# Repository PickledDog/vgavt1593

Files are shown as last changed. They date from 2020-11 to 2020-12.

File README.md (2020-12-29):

# vgavt1593
 Marco Maccaferri's Propeller VT100 Terminal, in a box
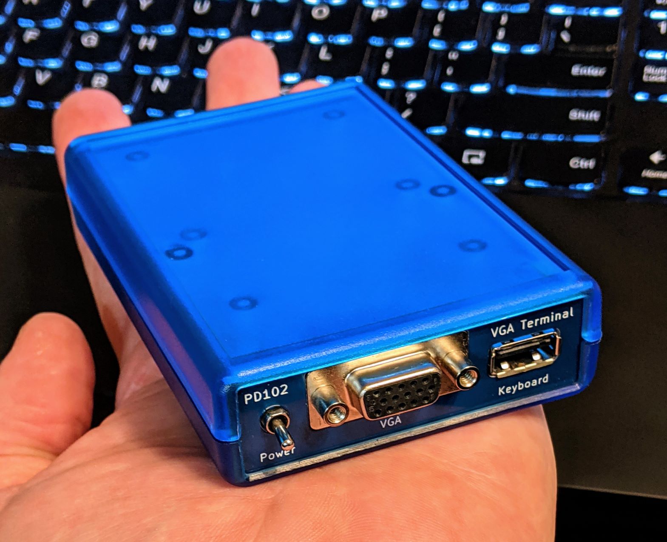
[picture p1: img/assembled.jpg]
Assembled VGA terminal


## Overview
This is a remix of Marco Maccaferri's [VGA Serial Terminal](https://github.com/maccasoft/propeller-vt100-terminal) for RC2014. It is specifically adapted to be used with Stephen C Cousins' [SC131](https://smallcomputercentral.wordpress.com/sc131-z180-pocket-computer/) Z180 pocket computer. It fits into the same Hammond 1593N enclosure, making for a neat and tidy setup when combined with an SC131. Of course, it can also be used with any other retrocomputer or device that expects a VT100-like terminal, connected over "TTL-Serial" raw RS232.

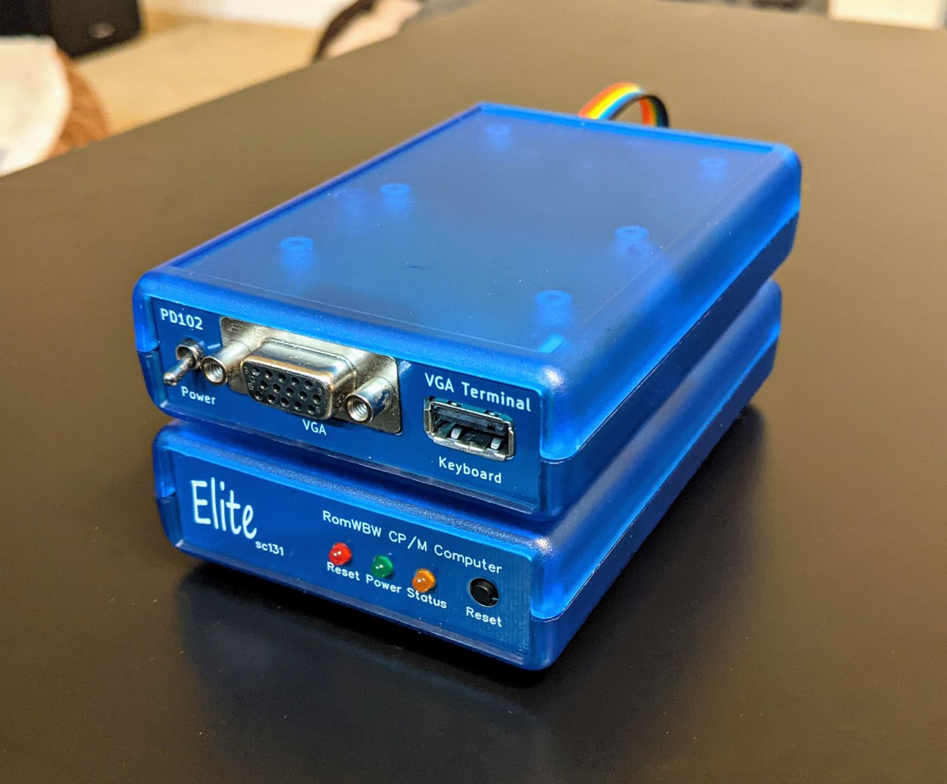
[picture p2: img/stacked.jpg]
Stacked with SC131

VGA terminal stacked with SC131 computer

## Terminal description
Details about the terminal itself are covered by Marco's project (this remix largely just changes the form factor). For detailed information, see his [project page](https://github.com/maccasoft/propeller-vt100-terminal).

## Serial interfaces
Connection to a computer is provided through an FTDI-style pin header, wired to the same pinout. Specifically, it is wired as a DTE (just like an FTDI dongle), so it can be wired directly to a DCE (like an SC131). A second *passthrough* port is provided to permit a PC connection to the same computer. This passthrough port is wired as a DCE, so FTDI cables can be connected directly. An AND gate mixes the terminal and passthrough connections together, so both can be used simultaneously. Transmitting from both at the same time will send gibberish; in testing this is relatively rare, and XMODEM at least will retransmit if this happens.

## Usage
This terminal lets you use your SC131 (or other retrocomputer) standalone, without dependency on another computer. In addition, a modern computer can be connected to the passthrough port as needed. This is useful for sending files over XMODEM, for example.

### Power
5V power is received through a standard 5.5/2.1mm barrel jack connection, center positive. The device optionally sends power to the connected computer (selectable by a jumper on JP1 - this is expected by SC131). In most cases, JP1 should be left installed. Wall adapters in this voltage and configuration are common, or a USB to 5.5mm cable can be used (examples [here](https://www.ebay.com/sch/i.html?_nkw=usb+to+5.5mm)).

### Why are the plugs on the front?
Because I ran out of room on the enclosure's panels. Between two FTDI headers, 5V in, reset, power switch, VGA, and USB, there wasn't even room left for a power LED. The serial ports are on the same side as the SC131 ones at least, so those can be connected together cleanly with a [6-pin Dupont cable](https://www.ebay.com/sch/i.html?_nkw=6+pin+dupont+cable).

### Initial setup
The parts specified are not pre-programmed; they will need to be programmed before use. Either a [Prop-Plug](https://www.mouser.com/ProductDetail/32201) can be used on the assembled board, or a [TL866](https://www.ebay.com/sch/i.html?_nkw=tl866ii+plus) or [CH341](https://www.ebay.com/sch/i.html?_nkw=ch341a+programmer) can be used on the bare EEPROM. Instructions (and firmware) for programming can be found at the same [link](https://github.com/maccasoft/propeller-vt100-terminal) as above.

## Part selection
Bill Of Materials and part references are below. Note that the right-angle headers have to be a specific type to align with the panel PCBs - they need to have the plastic "end stopper" on the "business" side of the angle, *not* the side you solder to the PCB. Headers from [Pololu](https://www.pololu.com/product/967), [Sparkfun](https://www.sparkfun.com/products/553), and [Adafruit](https://www.adafruit.com/product/1540) are like this, as is the Mouser listing below. Most eBay etc listings are ***not*** like this, and will not align correctly. If the appropriate headers cannot be sourced, double-row right-angle headers can be used, with the top row of pins removed.

The other headers can be snapped from regular breakaway header, for which eBay is substantially cheaper; the Mouser listings are provided for convenience. The specified parts are just the ones I used, and can be substituted as needed - Mouser links provided for convenience and reference. The case is available in other colours!

| Reference | Value | Qty | Mouser link |
| --- | ----- | --- | --- |
| BZ1 | Piezo buzzer | 1 | [TDK PS1240P02BT](https://www.mouser.com/ProductDetail/810-PS1240P02BT) |
| C1, C2 | 1μF ceramic | 2 | [TDK FG18X5R1H105KRT06](https://www.mouser.com/ProductDetail/FG18X5R1H105KRT06) |
| C3-C7 | 100nF ceramic | 5 | [KEMET C315C104M5U5TA](https://www.mouser.com/ProductDetail/C315C104M5U5TA7303) |
| C8 | 10μF electrolytic | 1 | [Nichicon UMA1E100MDD](https://www.mouser.com/ProductDetail/UMA1E100MDD) |
| J1 | 5.5/2.1mm barrel socket | 1 | [CUI PJ-002A](https://www.mouser.com/ProductDetail/490-PJ-002A) |
| J2 | 1x4 header | 1 | [Amphenol 10129378-904002BLF](https://www.mouser.com/ProductDetail/10129378-904002BLF) |
| J3, J4 | 1x6 right-angle header | 2 | [Amphenol 10129379-906003BLF](https://www.mouser.com/ProductDetail/10129379-906003BLF) |
| J5 | USB A socket | 1 | [Amphenol FCI 87520-1110BLF](https://www.mouser.com/ProductDetail/649-87520-1110BLF) |
| J6 | D-Sub HD-15 Female | 1 | [TE 2311763-1](https://www.mouser.com/ProductDetail/571-2311763-1) |
| JP1 | 1x2 header | 1 | [Amphenol 10129378-902002BLF](https://www.mouser.com/ProductDetail/10129378-902002BLF) |
| | jumper | 1 | [Harwin M7583-46](https://www.mouser.com/ProductDetail/M7583-46)
| R1, R4 | 10kΩ resistor | 2 | [Yageo CFR-25JT-52-10K](https://www.mouser.com/ProductDetail/CFR-25JT-52-10K) |
| R2, R3 | 4k7Ω resistor | 2 | [Yageo CFR-25JT-52-4K7](https://www.mouser.com/ProductDetail/CFR-25JT-52-4K7) |
| R5, R8 | 47kΩ resistor | 2 | [Yageo CFR-25JT-52-47K](https://www.mouser.com/ProductDetail/CFR-25JT-52-47K) |
| R6, R7 | 47Ω resistor | 2 | [Yageo CFR-25JT-52-47R](https://www.mouser.com/ProductDetail/CFR-25JT-52-47R) |
| R9, R12, R15 | 261Ω resistor | 3 | [Yageo MFR-25FRF52-261R](https://www.mouser.com/ProductDetail/603-MFR-25FRF52-261R) |
| R10, R13, R16 | 510Ω resistor | 3 | [Yageo MFR-25FTE52-510R](https://www.mouser.com/ProductDetail/603-MFR-25FTE52-510R) |
| R11, R14, R17-R19 | 120Ω resistor | 5 | [Yageo MFR-25FTF52-120R](https://www.mouser.com/ProductDetail/603-MFR-25FTF52-120R) |
| SW1 | SPDT toggle sw, right-angle | 1 | [Grayhill 34CMSP12B2M7QT](https://www.mouser.com/ProductDetail/706-34CMSP12B2M7QT) |
| SW2 | Right-angle tact sw 8.3mm | 1 | [C&K PTS645VL832LFS](https://www.mouser.com/ProductDetail/611-PTS645VL832) |
| U1 | Parallax Propeller | 1 | [Parallax Propeller P8X32A-D40](https://www.mouser.com/ProductDetail/619-P8X32A-D40) |
| | socket | 1 | [Amphenol DILB40P-223TLF](https://www.mouser.com/ProductDetail/DILB40P-223TLF) |
| U2 | 24LC256 EEPROM | 1 | [Microchip 24LC256](https://www.mouser.com/ProductDetail/579-24LC256-I-P) |
| | socket | 1 | [Amphenol DILB8P-223TLF](https://www.mouser.com/ProductDetail/DILB8P-223TLF) |
| U3 | MCP1700-330 | 1 | [Microchip MCP1700-3302E/TO](https://www.mouser.com/ProductDetail/579-MCP1700-3302E-TO) |
| U4 | 74HC08 | 1 | [TI SN74HC08AN](https://www.mouser.com/ProductDetail/595-SN74HC08AN) |
| X1 | 5MHz HC-49 crystal | 1 | [ECS ECS-50-18-4XEN](https://www.mouser.com/ProductDetail/520-50-18-4XEN) |
| Case | Hammond 1593N | 1 | [Hammond 1593NTBU](https://www.mouser.com/ProductDetail/546-1593NTBU) |
| Screws | Hammond self-tapping | (some of) | [Hammond 1593ATS](https://www.mouser.com/ProductDetail/546-1593ATS100) |

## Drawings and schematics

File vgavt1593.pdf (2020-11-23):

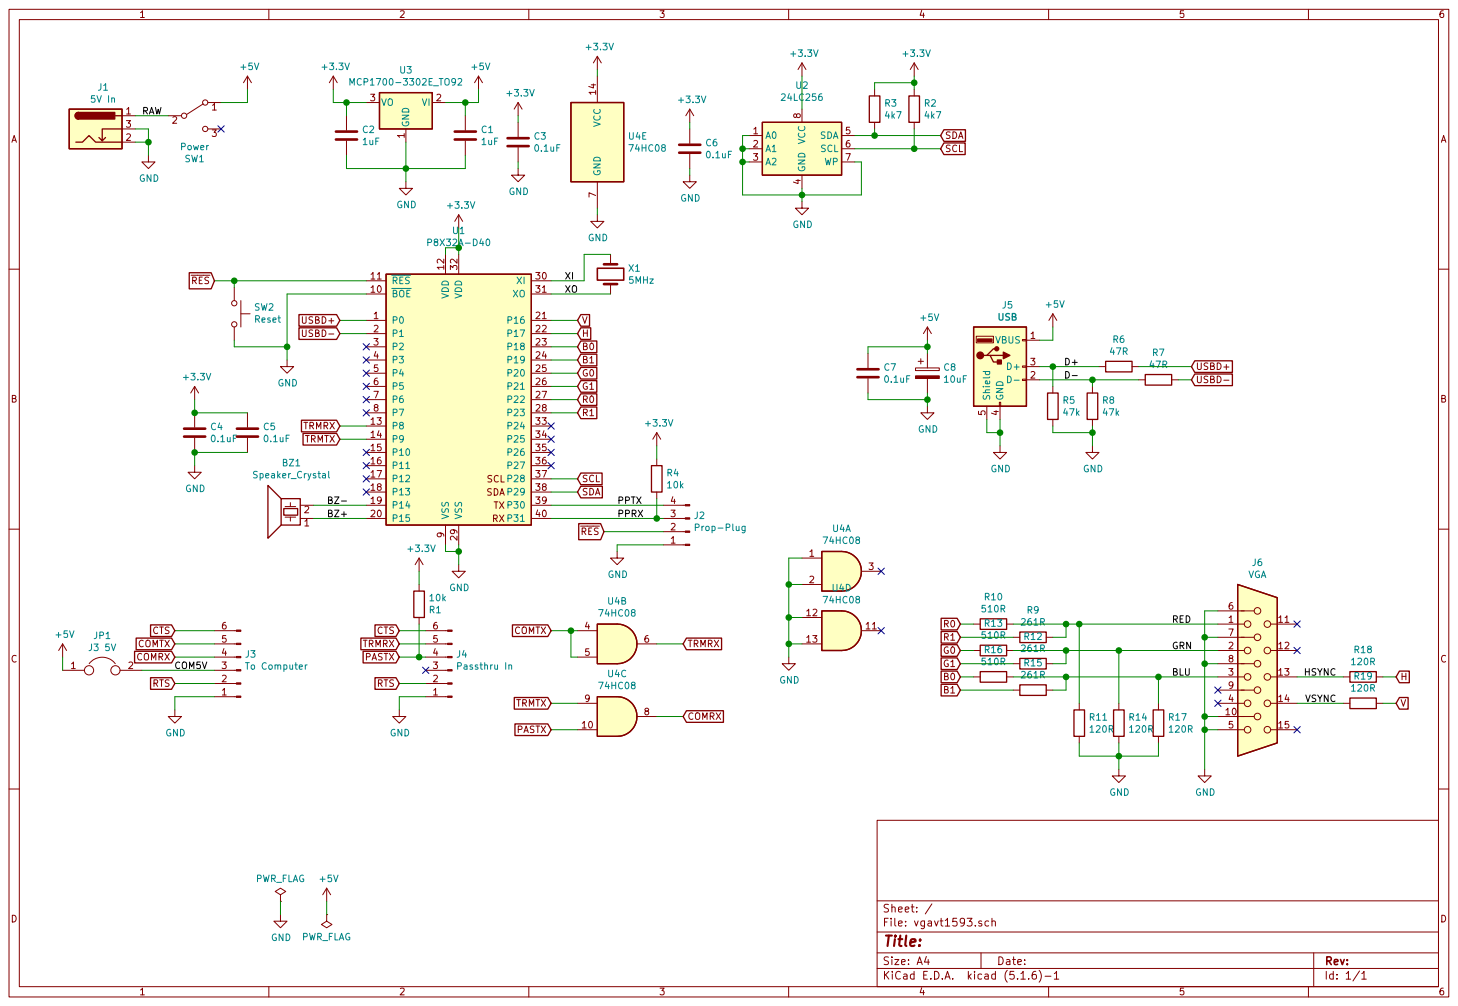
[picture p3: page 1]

1 VI 2 VO 3 U3 MCP1700-3302E_TO92 +3.3V GND GND GND

4 SDA 5 SCL 6 WP 7 VCC

9 BOE 10 P15 20 XI 30 P31 40 RES 11 P16 21 XO 31 VDD 12 P17 22 VDD 32 P8 13 P18 23 P24 33 P9 14 P19 24 P25 34 P10 15 P20 25 P26 35 P11 16 P21 26 P27 36 P12 17 P22 27 P28 37 P13 18 P23 28 P29 38 P14 19 VSS 29 P30 39 U1 P8X32A-D40 R4

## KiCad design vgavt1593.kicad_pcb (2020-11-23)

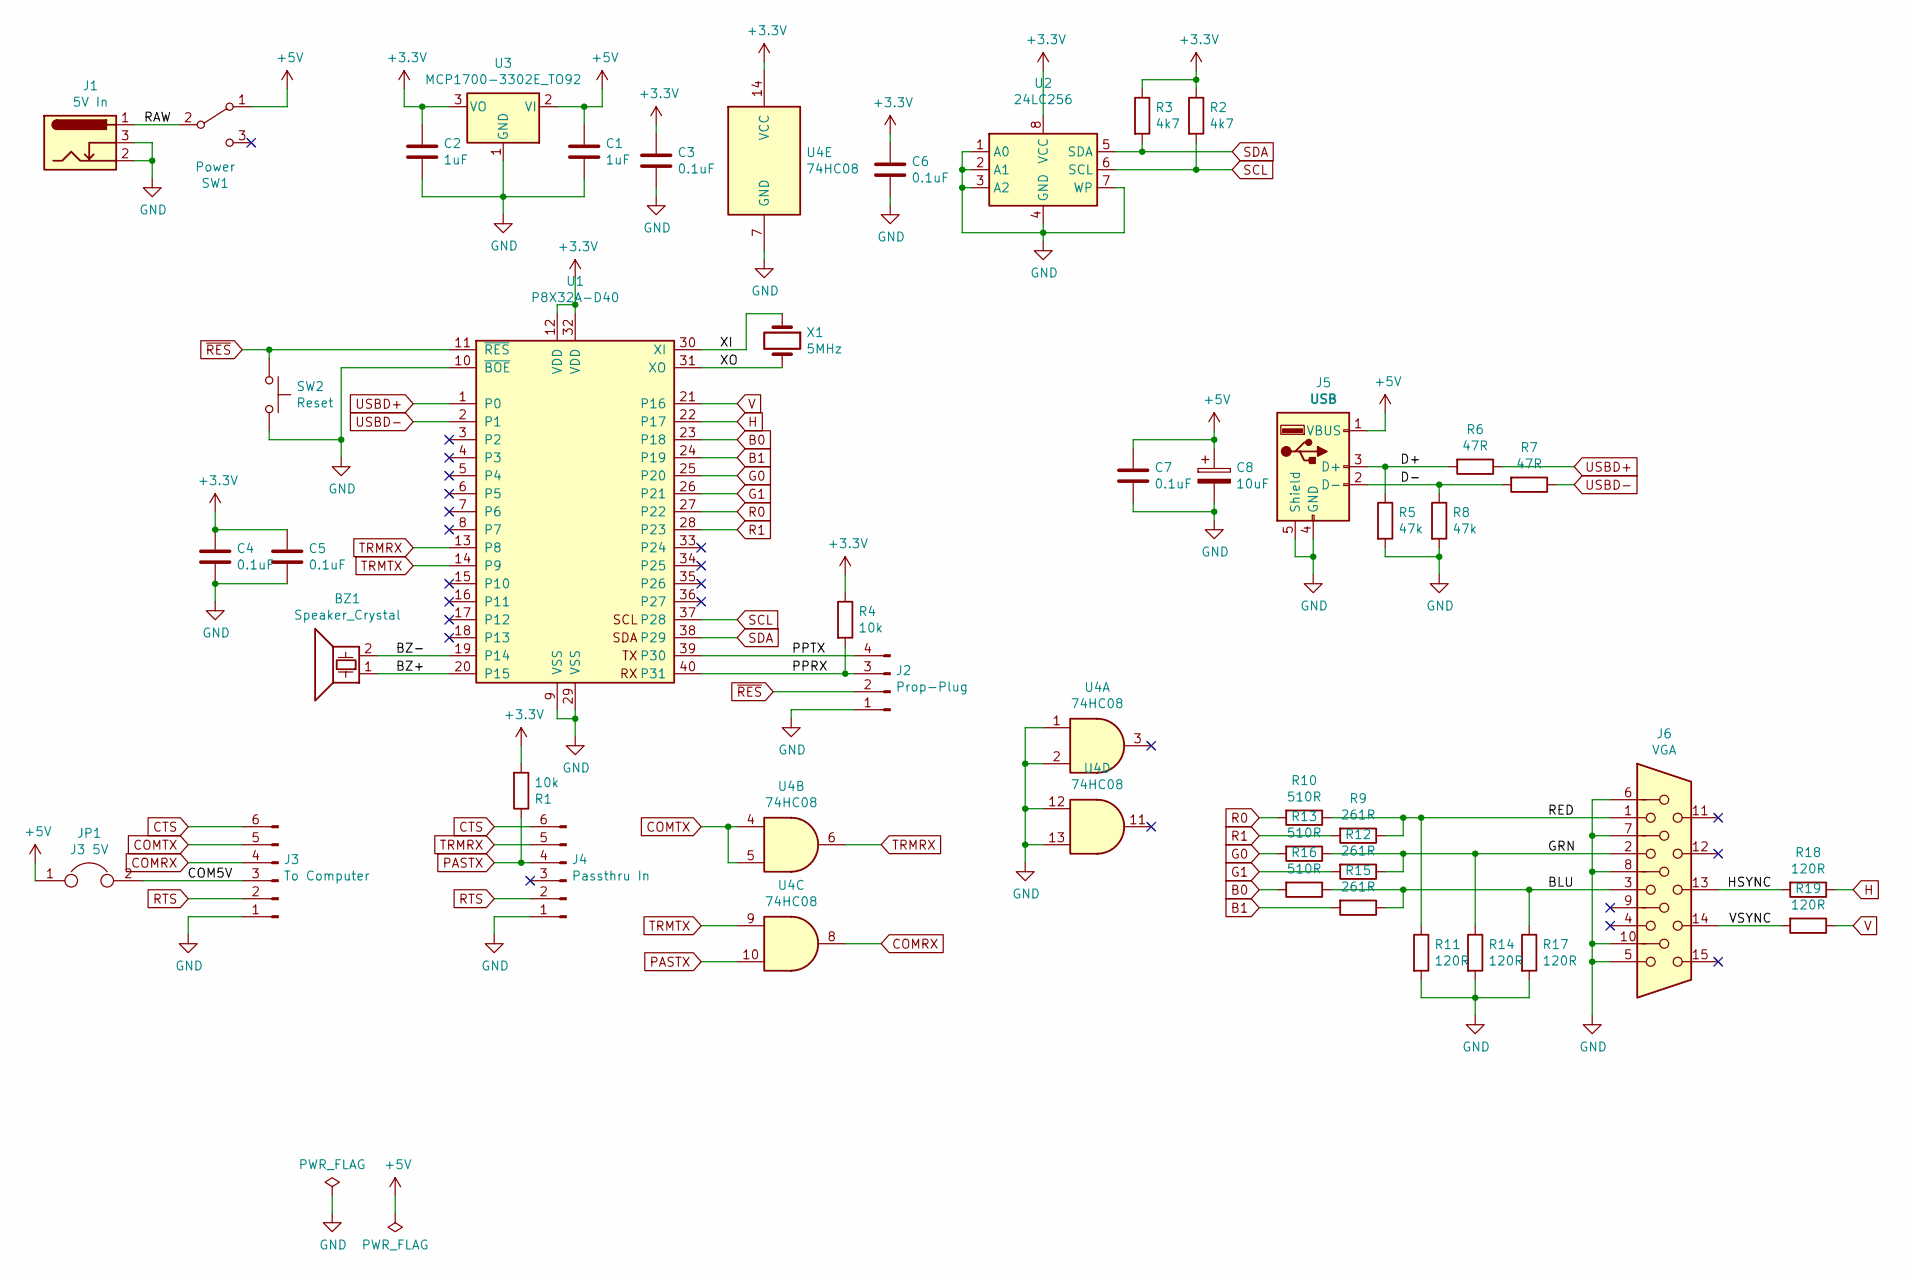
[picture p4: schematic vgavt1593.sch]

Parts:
BZ1: Speaker_Crystal; Buzzer_TDK_PS1240P02BT_D12.2mm_H6.5mm
C1, C2: 1uF; C_Disc_D3.0mm_W1.6mm_P2.50mm
C3, C4, C5, C6, C7: 0.1uF; C_Disc_D3.0mm_W1.6mm_P2.50mm
C8: 10uF; CP_Radial_D5.0mm_P2.00mm
J1: 5V In; BarrelJack_Horizontal
J2: Prop-Plug; PinHeader_1x04_P2.54mm_Vertical
J3: To Computer; PinHeader_1x06_P2.54mm_Vertical
J4: Passthru In; PinHeader_1x06_P2.54mm_Vertical
J5: USB; USB_A_CONNFLY_DS1095-WNR0
J6: VGA; DSUB-15-HD_Female_Horizontal_P2.29x2.54mm_Housed
JP1: J3 5V; PinHeader_1x02_P2.54mm_Vertical
R1, R4: 10k; R_Axial_DIN0207_L6.3mm_D2.5mm_P7.62mm_Horizontal
R2, R3: 4k7; R_Axial_DIN0207_L6.3mm_D2.5mm_P7.62mm_Horizontal
R5, R8: 47k; R_Axial_DIN0207_L6.3mm_D2.5mm_P7.62mm_Horizontal
R6, R7: 47R; R_Axial_DIN0207_L6.3mm_D2.5mm_P7.62mm_Horizontal
R9, R12, R15: 261R; R_Axial_DIN0207_L6.3mm_D2.5mm_P7.62mm_Horizontal
R10, R13, R16: 510R; R_Axial_DIN0207_L6.3mm_D2.5mm_P7.62mm_Horizontal
R11, R14, R17, R18, R19: 120R; R_Axial_DIN0207_L6.3mm_D2.5mm_P7.62mm_Horizontal
SW1: Power; SW_Toggle_SPDT_Vertical
SW2: Reset; SW_Tactile_SPST_Angled_PTS645Vx83-2LFS
U1: P8X32A-D40; DIP-40_W15.24mm_LongPads
U2: 24LC256; DIP-8_W7.62mm_LongPads
U3: MCP1700-3302E_TO92; TO-92
U4: 74HC08; DIP-14_W7.62mm_LongPads
X1: 5MHz; Crystal_HC49-U_Vertical

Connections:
+3V3: C2.1, C3.1, C4.1, C5.1, C6.1, R1.2, R2.1, R3.1, R4.1, U1.12 (VDD), U1.32 (VDD), U2.8 (VCC), U3.3 (VO), U4.14 (VCC)
+5V: C1.1, C7.1, C8.1, J5.1 (VBUS), JP1.1, SW1.1 (A), U3.2 (VI)
/BLU: J6.3, R15.1, R16.1, R17.1
/BZ+: BZ1.1, U1.20 (P15)
/BZ-: BZ1.2, U1.19 (P14)
/COM5V: J3.3, JP1.2
/D+: J5.3 (D+), R5.1, R6.2
/D-: J5.2 (D-), R7.2, R8.1
/GRN: J6.2, R12.1, R13.1, R14.1
/HSYNC: J6.13, R18.2
/PPRX: J2.3, R4.2, U1.40 (P31)
/PPTX: J2.4, U1.39 (P30)
/RAW: J1.1, SW1.2 (B)
/RED: J6.1, R9.1, R10.1, R11.1
/VSYNC: J6.14, R19.2
/XI: U1.30 (XI), X1.1
/XO: U1.31 (XO), X1.2
B0: R16.2, U1.23 (P18)
B1: R15.2, U1.24 (P19)
COMRX: J3.4, U4.8
COMTX: J3.5, U4.4, U4.5
CTS: J3.6, J4.6
G0: R13.2, U1.25 (P20)
G1: R12.2, U1.26 (P21)
GND: C1.2, C2.2, C3.2, C4.2, C5.2, C6.2, C7.2, C8.2, J1.2, J1.3, J2.1, J3.1, J4.1, J5.4 (GND), J5.5 (Shield), J6.5, J6.6, J6.7, J6.8, J6.10, R5.2, R8.2, R11.2, R14.2, R17.2, SW2.1, U1.9 (VSS), U1.10 (~BOE), U1.29 (VSS), U2.1 (A0), U2.2 (A1), U2.3 (A2), U2.4 (GND), U2.7 (WP), U3.1 (GND), U4.1, U4.2, U4.7 (GND), U4.12, U4.13
H: R18.1, U1.22 (P17)
PASTX: J4.4, R1.1, U4.10
R0: R10.2, U1.27 (P22)
R1: R9.2, U1.28 (P23)
RTS: J3.2, J4.2
SCL: R2.2, U1.37 (P28), U2.6 (SCL)
SDA: R3.2, U1.38 (P29), U2.5 (SDA)
TRMRX: J4.5, U1.13 (P8), U4.6
TRMTX: U1.14 (P9), U4.9
USBD+: R6.1, U1.1 (P0)
USBD-: R7.1, U1.2 (P1)
V: R19.1, U1.21 (P16)
~RES: J2.2, SW2.2, U1.11 (~RES)

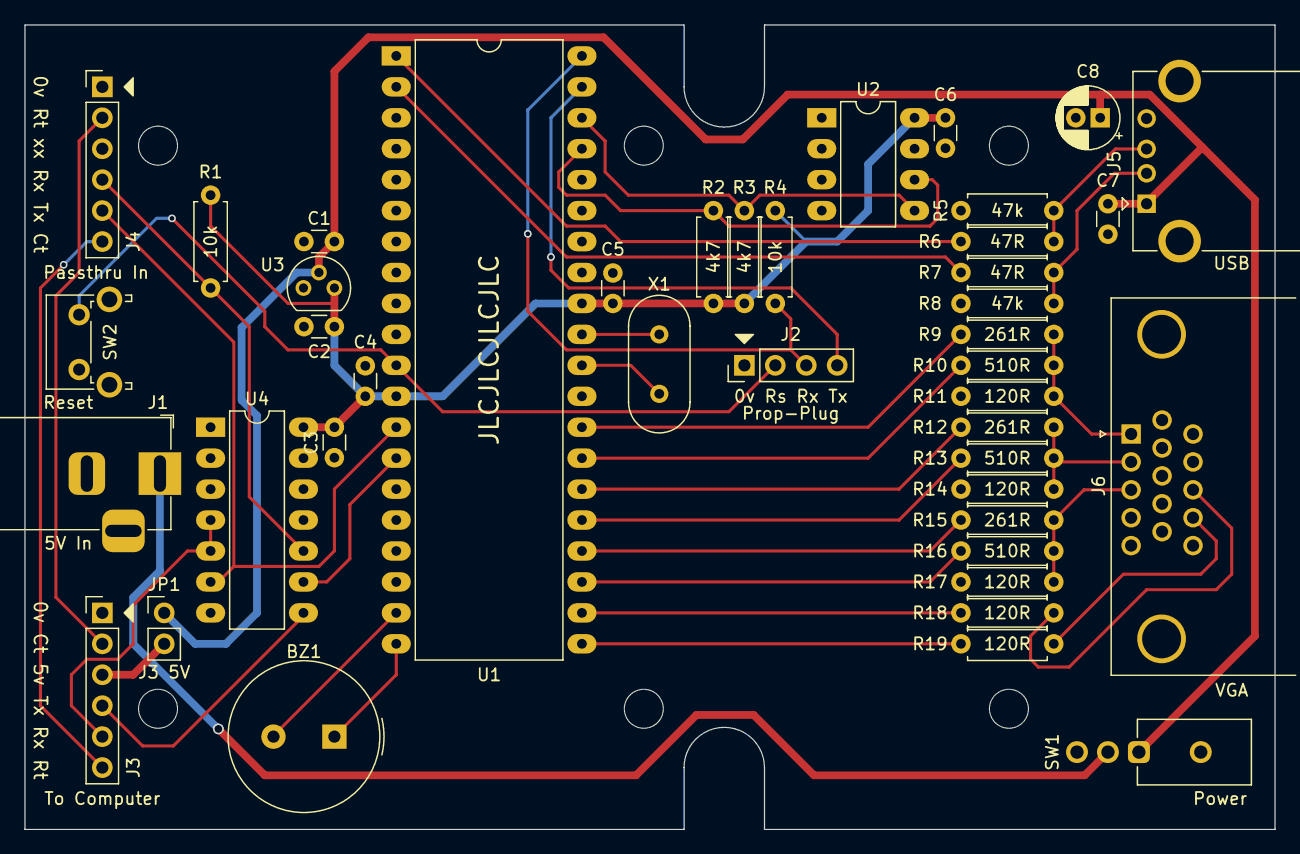
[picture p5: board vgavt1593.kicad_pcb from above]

Board: 2 copper layers, 102.6 x 66.0 mm, 48 parts (0 on the bottom side), 38 nets.

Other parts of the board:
MK1, MK2, MK3, MK4, MK5, MK6: Mounting_Hole; MountingHole_3.2mm_M3_ISO7380

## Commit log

2020-11-23 Initial commit of vgavt1593
    Initial commit of vgavt1593/PD102
    [vgavt1593-B_Cu.gbl, vgavt1593-B_Mask.gbs, vgavt1593-B_SilkS.gbo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]
2020-12-09 Update README.md
    Add case links and programming notes
2020-12-09 UART dyslexia
2020-12-11 Tweak README and BOM
2020-12-27 Update README.md
    Added link to buy Dupont cable

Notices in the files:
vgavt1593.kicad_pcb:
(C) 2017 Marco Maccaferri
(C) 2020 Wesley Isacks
